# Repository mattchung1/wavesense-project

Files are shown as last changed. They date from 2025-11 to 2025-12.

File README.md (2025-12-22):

# WaveSense: Haptic Navigation for the Visually Impaired





WaveSense is an assistive technology wearable designed to enhance spatial awareness for visually impaired individuals. By converting environmental data—distance and temperature—into intuitive haptic feedback, the device provides a "sixth sense" for navigation and safety.

## Project Demo

Check out the device in action:

Watch the Demo (https://youtube.com/shorts/ASVKNsmMCBw)

> *Click the image above to watch the demonstration video.*

## Project Files
PCB view for the Wavesense

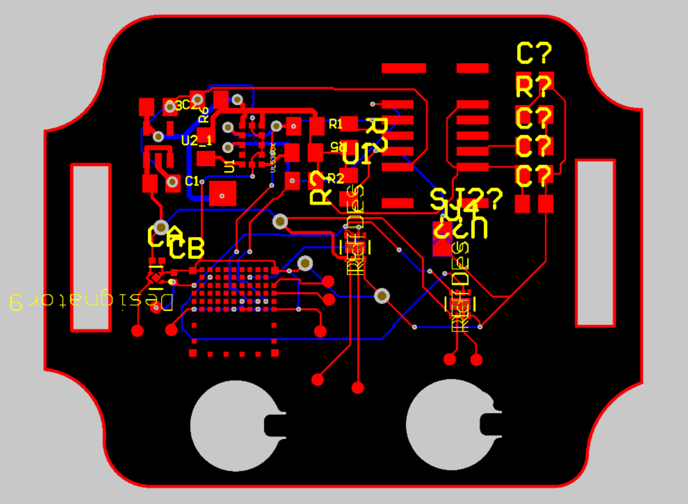
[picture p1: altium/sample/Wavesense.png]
PCB Layout View


SCH View for the Wavesense

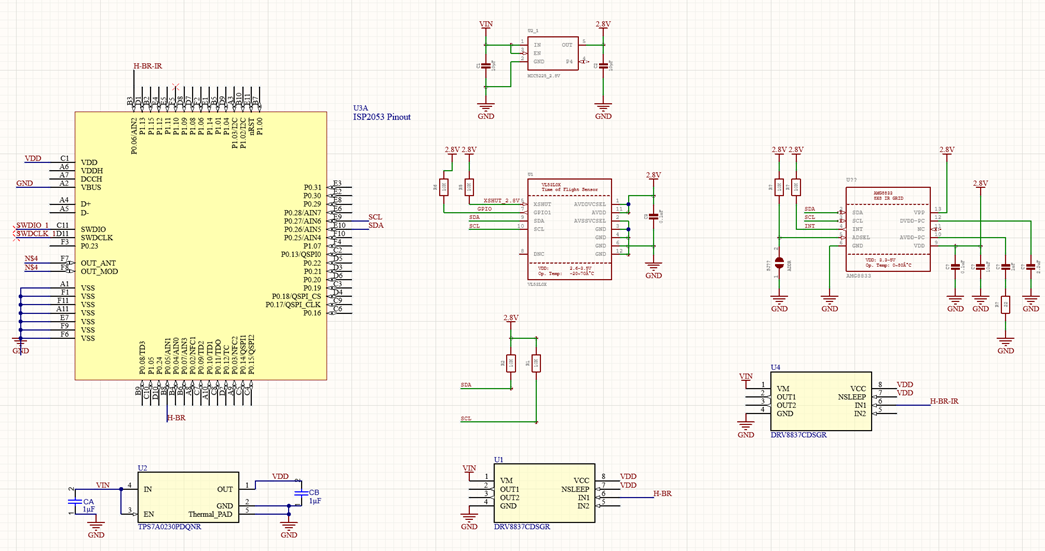
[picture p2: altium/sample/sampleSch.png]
SCH Layout View


## Repository Structure

This repository is organized into two primary engineering domains:

```text
WaveSense/
├── firmware/          # Embedded C code built on the Zephyr RTOS (nRF Connect SDK)
│   ├── src/           # Application source code (main.c, sensor logic)
│   ├── boards/        # Custom board overlays and configuration
│   └── prj.conf       # Kernel configuration (sensor drivers, logging, RTT)
│
└── altium/            # Hardware Design Files
    ├── examples/    # Circuit design and connectivity    
    └── .Sch / .Pcb    # Component placement and routing
```

## Key Features

The system utilizes a dual-haptic feedback loop to communicate two distinct environmental factors:

1.  **Proximity Navigation (ToF Sensor):**
    * Utilizes a **VL53L0X Time-of-Flight sensor** to measure distance to obstacles.
    * **Inverse Haptic Mapping:** As the user's hand gets closer to an object, the vibration intensity of the primary motor increases linearly, mimicking the sensation of "touching" the object remotely.

2.  **Thermal Safety Alert (IR Array):**
    * Utilizes a **Panasonic AMG8833 IR Array** (Grid-EYE) to detect heat sources.
    * **Threshold Trigger:** If an object in the field of view exceeds a safety threshold (e.g., a hot stove or machinery), a secondary vibration motor triggers a distinct alert pattern.

## Hardware Specifications

* **Microcontroller:** Nordic Semiconductor nRF5340 (Dual-core ARM Cortex-M33)
* **Operating System:** Zephyr RTOS / nRF Connect SDK (v2.9.0)
* **Sensors:**
    * STMicroelectronics VL53L0X (ToF Distance)
    * Panasonic AMG8833 (8x8 IR Temperature Array)
* **Actuators:** 2x ERM/LRA Vibration Motors (PWM controlled via MOSFET drivers)

## Pinout Configuration

| Component | nRF5340 Pin | Bus/Protocol |
| :--- | :--- | :--- |
| **I2C SDA** | P0.26 | I2C1 |
| **I2C SCL** | P0.27 | I2C1 |
| **Haptic Motor 1 (Dist)** | P0.05 | PWM0 |
| **Haptic Motor 2 (Temp)** | P0.06 | PWM2 |

## Getting Started

### Prerequisites
* [nRF Connect SDK](https://www.nordicsemi.com/Software-and-tools/Software/nRF-Connect-SDK)
* Visual Studio Code with nRF Connect Extension

### Build & Flash
To build the firmware for the nRF5340 DK:

1.  Open the `firmware` folder in VS Code.
2.  Add a build configuration for `nrf5340dk_nrf5340_cpuapp`.
3.  Run a pristine build.
4.  Flash to the device using `west flash` or the nRF Connect sidebar.

```bash
cd firmware
west build -b nrf5340dk_nrf5340_cpuapp
west flash

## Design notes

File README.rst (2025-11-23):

Overview
********

This sample periodically measures distance between vl53l0x sensor
and target. The sample also periodically measures surface temperature 
of the object using the amg88xx sensor. The user is meant to wave 
their hand in order to detect objects and subsequently receive a 
haptic feedback proportional to the distance from the user to the 
target. They also receive a separate haptic feedback signal for when 
detecting an object that would be too hot to touch. This is a 
reconfigurable portion of the device

Both the hardware and firmware were made in collaboration with 
Andrew Liu and Matt Chung.

Requirements
************

This firmware sample requires the use of the nordic library. These can be
installed from a VS Code extension:
https://docs.nordicsemi.com/bundle/nrf-connect-vscode/page/get_started/quick_setup.html

The repository that the above extension can be found here:
https://github.com/zephyrproject-rtos/zephyr/tree/main/samples

In order to use the sample, an board with a VL53L0X and AMG88xx connected by
I2C to an ISP is required. Two outputs from the ISP should be PWM signals running
to 2 different H-bridges connected to their own motors.

The firmware code uses sample header files from Zephyr and this file should be 
placed in the directory:
~/ncs/v2.9.0/zephyr/wavesense-firmware-amg88xx-vl53

References
**********

 - VL53L0X: https://www.st.com/en/imaging-and-photonics-solutions/vl53l0x.html
 - AMG88xx: https://learn.adafruit.com/adafruit-amg8833-8x8-thermal-camera-sensor/overview

Sample Output
=============

 .. code-block:: console

  00> 
  00> Distance: 2137 mm
  00> Object output high time of 0ns 
  00> Duty Cycle: 0
  00> new sample:
  00> 
  00> Distance: 2093 mm
  00> Object output high time of 0ns 
  00> Duty Cycle: 0
  00> new sample:
  00> 
  00> Temperature above threshold! Activating alert servo.
  00> Distance: 2107 mm
  00> Object output high time of 0ns 
  00> Duty Cycle: 0
  00> new sample:
  00> 
  00> Temperature above threshold! Activating alert servo.
  00> Distance: 116 mm
  00> Object output high time of 15699832ns 
  00> Duty Cycle: 78
  00> new sample:
  00> 
  00> Temperature above threshold! Activating alert servo.
  00> Distance: 60 mm
  00> Object output high time of 18060709ns 
  00> Duty Cycle: 90
  00> new sample:
  00>

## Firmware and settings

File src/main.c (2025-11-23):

// Firmware code for Wavesense device that uses VL53L0X and AMG88xx sensors

/* Portions of this file derived from VL53L0X driver
 *	
 * Copyright (c) 2017 STMicroelectronics
 *
 * SPDX-License-Identifier: Apache-2.0
 */


#include <zephyr/kernel.h>
#include <zephyr/device.h>
#include <zephyr/drivers/sensor.h>
#include <zephyr/logging/log.h>
#include <zephyr/devicetree.h>
#include <zephyr/drivers/gpio.h>
#include <stdio.h>
#include <zephyr/sys/printk.h>
#include <zephyr/dt-bindings/pinctrl/nrf-pinctrl.h>

#include <zephyr/drivers/pwm.h>

LOG_MODULE_REGISTER(ECE8873, LOG_LEVEL_INF);

#define LED0_NODE  DT_ALIAS(led0)
static const struct gpio_dt_spec led0 = GPIO_DT_SPEC_GET(LED0_NODE, gpios);

/* Get the first VL53L0X device from devicetree */
static const struct device *const tof = DEVICE_DT_GET_ANY(st_vl53l0x);

/* Choose your threshold (millimeters) */
#define THRESH_MM 200  /* LED on when distance < 200 mm */

// Define the servo motor parameters
#define SERVO_MOTOR1     DT_NODELABEL(servo1)
static const struct pwm_dt_spec pwm_servo1 = PWM_DT_SPEC_GET(SERVO_MOTOR1);

// Define another PWM for temperature alert
#define SERVO_MOTOR2     DT_NODELABEL(servo2)
static const struct pwm_dt_spec pwm_servo2 = PWM_DT_SPEC_GET(SERVO_MOTOR2);


/* STEP 5.5 - Use DT_PROP() to obtain the minimum and maximum duty cycle */
#define PWM_SERVO_MIN_PULSE_WIDTH    DT_PROP(SERVO_MOTOR1, min_pulse)
#define PWM_SERVO_MAX_PULSE_WIDTH    DT_PROP(SERVO_MOTOR1, max_pulse)
#define PWM_PERIOD   PWM_MSEC(20)
#define PWM_FREQUENCY PWM_MSEC(10)
/* STEP  2.2 - Define minimum and maximum duty cycle */
/* STEP 4.2 - Change the duty cycles for the LED */
#define PWM_MIN_PULSE_WIDTH 0
#define PWM_MAX_PULSE_WIDTH 50000000

/* STEP 2.1 - Create a function to set the angle of the motor */
/* STEP 5.8 - Change set_motor_angle() to use the pwm_servo device */
int set_motor_angle(uint32_t pulse_width_ns)
{
    int err;
    err = pwm_set_dt(&pwm_servo1, PWM_PERIOD, pulse_width_ns);
    if (err) {
        LOG_ERR("pwm_set_dt_returned %d", err);
    }
    return err;
}


// Define for IR Temperature Sensor
#define VL_NODE  DT_COMPAT_GET_ANY_STATUS_OKAY(st_vl53l0x)
#define AMG_NODE DT_COMPAT_GET_ANY_STATUS_OKAY(panasonic_amg88xx)

// Detects if nodes are ok
#if !DT_NODE_HAS_STATUS(VL_NODE, okay)
#error "No enabled VL53L0X node found in devicetree"
#endif

#if !DT_NODE_HAS_STATUS(AMG_NODE, okay)
#error "No enabled AMG88xx node found in devicetree (check overlay and int-gpios)"
#endif

// Structure to hold temp values from AMG
static struct sensor_value temp_value[64];

// Trigger handler for AMG88xx
#ifdef CONFIG_AMG88XX_TRIGGER
K_SEM_DEFINE(sem, 0, 1);

static void trigger_handler(const struct device *dev,
			    const struct sensor_trigger *trigger)
{
	ARG_UNUSED(dev);
	ARG_UNUSED(trigger);

	k_sem_give(&sem);
}
#endif

bool isAboveThreshold = false;

/*
************
USER SET VARIABLES
************
*/
int thresholdTemperature = 30; // Temperature threshold in Celsius




/*
************
FUNCTIONS
************
*/
// Function for AMG printing buffer
void print_buffer(void *ptr, size_t l)
{
	struct sensor_value *tv = ptr;
	int ln = 0;

	//printk("---|");
	for (int i = 0; i < 8; i++) {
		//printk("  %02d  ", i);
	}
	//printk("\n");

	// This is value of integer part
	int tempVal1 = tv[0].val1;
	// This is value of fractional / decimal part
	int tempVal2 = tv[0].val2;

	// for loop to print the values in a grid
	//printk("%03d|", ln);
	for (int i = 0; i < l; i++) {

		// Added these for formatting and calculations
		tempVal1 = tv[i].val1;
		tempVal2 = tv[i].val2;

		// Reformatted print to show decimal values
		// First is multiplying integer part by 100 to shift decimal
		// Second is dividing fractional part by 10000 to get two decimal places

		//printk("%05d ", (tempVal1 * 100 + tempVal2 / 10000));
		if (!((i + 1) % 8)) {
			//printk("\n");
			ln++;
			//printk("%03d|", ln);
		}

		// Calculate if any temperature in the grid is over threshold temperature
		if (tempVal1 >= thresholdTemperature)
		{
			isAboveThreshold = true;
		}
	}
	printk("\n");
}



// Function to map distance in mm to frequency for the motor
int mmToFrequency(int input)
{
	// Defining variables. Modify the input and output ranges as needed.
	int output;
	int input_start = 14;
	int input_end = 1200;
	int output_start = PWM_MIN_PULSE_WIDTH;
	int output_end = PWM_MAX_PULSE_WIDTH;

	// Calculating the slope and output value
	double slope = 1.0 * (output_end - output_start) / (input_end - input_start);
	output = output_start + slope * (input - input_start);
    //output = output_start + (input_end - input) * slope;
	return output;			
}


/*
************
MAIN CODE
************
*/
int main(void)
{
	// Initializing devices and variables
	static const struct device *const VL53  = DEVICE_DT_GET(VL_NODE);
	static const struct device *const AMG = DEVICE_DT_GET(AMG_NODE);
	struct sensor_value value;
	int ret;
	int err = 0;
	

	if (!device_is_ready(VL53)) {
		printk("sensor: vl53l0x device not ready.\n");
		//return 0;
	}
	if (!device_is_ready(AMG)) {
		printk("sensor: amg8833 device not ready.\n");
		//return 0;
	}
	if (!device_is_ready(led0.port)) {
        printk("LED0 GPIO not ready\n");
        return 0;
    }

	gpio_pin_configure_dt(&led0, GPIO_OUTPUT_INACTIVE);

	// ADDED FOR AMG8833
	#ifdef CONFIG_AMG88XX_TRIGGER
	struct sensor_value attr = {
		.val1 = 27,
		.val2 = 0,
	};

	if (sensor_attr_set(AMG, SENSOR_CHAN_AMBIENT_TEMP,
			    SENSOR_ATTR_UPPER_THRESH, &attr)) {
		printk("Could not set threshold\n");
		return 0;
	}

	struct sensor_trigger trig = {
		.type = SENSOR_TRIG_THRESHOLD,
		.chan = SENSOR_CHAN_AMBIENT_TEMP,
	};

	if (sensor_trigger_set(AMG, &trig, trigger_handler)) {
		printk("Could not set trigger\n");
		return 0;
	}
	#endif

	// ADDED FOR PWM
	/* STEP 5.7 - Check if the motor device is ready and set its initial value */
    if (!pwm_is_ready_dt(&pwm_servo1)) {
        LOG_ERR("Error: PWM device %s is not ready", pwm_servo1.dev->name);
        return 0;
    }

	err = pwm_set_dt(&pwm_servo1, PWM_PERIOD, PWM_SERVO_MIN_PULSE_WIDTH);
    if (err) {
        LOG_ERR("pwm_set_dt returned %d", err);
        return 0;
    }




	/*
	************
	MAIN LOOP
	************
	*/
	while (1) {

		// FOR AMG8833
		#ifdef CONFIG_AMG88XX_TRIGGER
		printk("Waiting for a threshold event\n");
		k_sem_take(&sem, K_FOREVER);
		#endif

		// Resetting isAboveThreshold flag
		isAboveThreshold = false;
		

		// FOR VL53
		ret = sensor_sample_fetch(VL53);
		if (ret) {
			printk("sensor_sample_fetch failed ret %d\n", ret);
			return 0;
		}
		
		ret = sensor_channel_get(VL53, SENSOR_CHAN_PROX, &value);
		//printk("prox is %d\n", value.val1);


		ret = sensor_channel_get(VL53,
					 SENSOR_CHAN_DISTANCE,
					 &value);
		//printf("distance is %.3fm\n", sensor_value_to_double(&value));

		// *** Adding code for eceClass ***
		// Turning on LED if object is close
		if (sensor_sample_fetch(tof) == 0) {
            struct sensor_value dist;

            if (sensor_channel_get(tof, SENSOR_CHAN_DISTANCE, &dist) == 0) {
                /* Convert Zephyr sensor_value to millimeters */
                /* dist is in meters; val1=int part, val2=micro part */
                double meters = sensor_value_to_double(&dist);
                int mm = (int)(meters * 1000.0 + 0.5);
				printk("Distance: %d mm\n", mm);

				int convertedF = mmToFrequency(mm);
				//int calculatedPulseWidthNS = mmToFrequency(mm);
				int calculatedPulseWidthNS = (20000000 - convertedF);


				if(calculatedPulseWidthNS < 0)
				{
					calculatedPulseWidthNS = 0;
				}
				pwm_set_dt(&pwm_servo1, PWM_PERIOD, calculatedPulseWidthNS);
				printk("Object output high time of %dns \nDuty Cycle: %d\n", calculatedPulseWidthNS, (calculatedPulseWidthNS*100)/20000000);

                /* If/else threshold */
				// if (mm > 0 && mm < THRESH_MM) {
				// 	printk("Object detected within %d mm\n", THRESH_MM);
				// 	pwm_set_dt(&pwm_servo, PWM_PERIOD, calculatedFrequency);
				// }
				// else{
				// 	pwm_set_dt(&pwm_servo, PWM_PERIOD, 0);
				// }

                //gpio_pin_set_dt(&led0, (mm > 0 && mm < THRESH_MM) ? 1 : 0);

				//set_motor_angle(PWM_SERVO_MAX_PULSE_WIDTH);
				
            }
        }

		// FOR AMG8833

		#ifdef CONFIG_AMG88XX_TRIGGER
		printk("Waiting for a threshold event\n");
		k_sem_take(&sem, K_FOREVER);
		#endif

		// continuing to use same ret int variable that we used for VL53
		ret = sensor_sample_fetch(AMG);

		if (ret) {
			printk("Failed to fetch a sample, %d\n", ret);
			//return 0;
		}

		ret = sensor_channel_get(AMG, SENSOR_CHAN_AMBIENT_TEMP,
					 (struct sensor_value *)temp_value);
		if (ret) {
			printk("Failed to get sensor values, %d\n", ret);
			//return 0;
		}

		// Calling print buffer to print the temperature values in an array
		//printk("new sample:\n");
		print_buffer(temp_value, ARRAY_SIZE(temp_value));

		//Turning on PWM if temperature is above threshold
		if(isAboveThreshold)
		{
			pwm_set_dt(&pwm_servo2, PWM_PERIOD, PWM_SERVO_MAX_PULSE_WIDTH);
			printk("Temperature above threshold! Activating alert servo.\n");
		}
		else
		{
			pwm_set_dt(&pwm_servo2, PWM_PERIOD, 0);
		}



		k_sleep(K_MSEC(100));

	}
	return 0;
}

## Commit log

2025-11-23 Refactor README.rst for clarity and formatting
    Removed code sample section and adjusted formatting.
2025-11-24 adding initial altium files
    [ECE8873_sample.PcbDoc, ECE8873_sample.SchDoc]
2025-12-22 Add project files section to README
    Added project files section with PCB and SCH views.
